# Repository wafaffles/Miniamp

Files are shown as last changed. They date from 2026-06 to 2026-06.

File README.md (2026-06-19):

# Miniamp
A portable, battery powered Hi-Fi DAC and headphone amplifier.

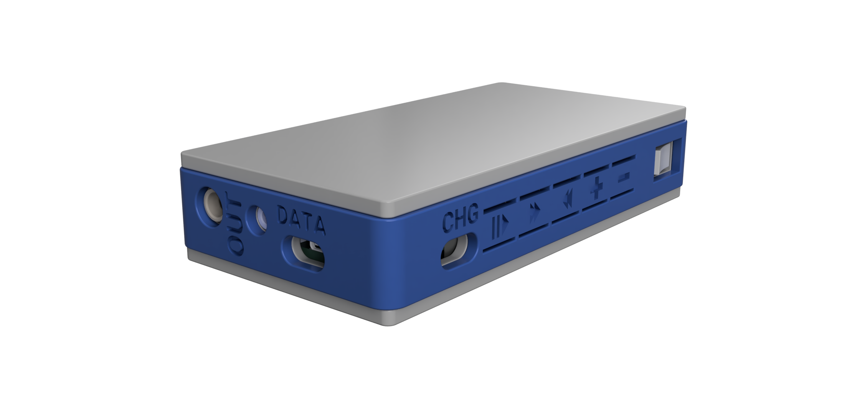
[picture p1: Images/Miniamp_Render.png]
Render of Miniamp in case


## Shortcuts
- [Features](#features)
- [What is it?](#what-is-it)
- [Resources](#resources)
- [Assembly](#assembly)
- [Bill Of Materials](#bill-of-materials)
- [Photos](#photos)

## Miniamp Zine

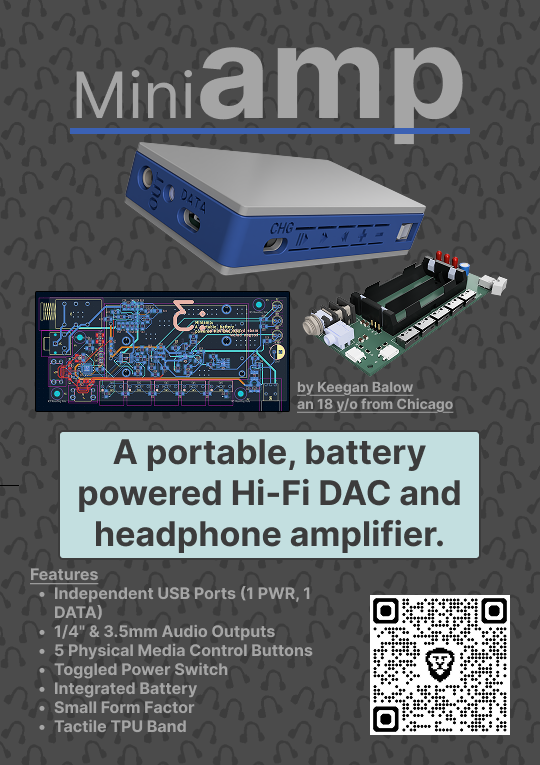
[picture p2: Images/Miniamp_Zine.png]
Miniamp Zine


## Features

- Independent USB-C Ports
  - Top Mounted Data Only USB-C
  - Side Mounted Power Only USB-C
- Variable Size Audio Outputs
  - 1/4"
  - 3.5mm
- 5 Physical Media Control Buttons
- Toggleable Power Switch
- 2 Integrated 18650 Batteries
  - Avoids Discharging Connected Device (e.g., Mobile Phone, Laptop)
- Small Form Factor

## What is it?

Miniamp is a portable, battery powered DAC and headphone amp designed for phones, portable devices, or for desk deployments. The Miniamp features a Hifi DAC chip capable of producing 24bit 44.1kHz outputs at 2.1Vrms, with adequite power for majority of headphones. It utilizes a Silicon Labs CP2615-A02-GM USB to I2S chip, a Cirrus Logic WM8524CGEDT DAC, and an Analog Devices MAX97220AETE+T headphone amplifier. It also has a battery charging and protection circuit to handle charing, protection, and output regulation to the ICs using 2 18650 batteries in a 1s2p configuration. This setup removes power draw from the data streaming device and offloads it to the batteries, with a passthrough power circuit to power all devices externally with a long battery life.

I created this to have an easy device to bring around with me at school so I can use my wired headphones and control them without the need to open my phone for controls or worry about my phone dying which was really nice. It should work well and do exactly that since I love the apple dongle, but its just super small, feels like its gonna break, and just kinda basic without any controls.
 
## Resources

CAD Link: https://cad.onshape.com/documents/a14a9a55c78bf32f82e1c97a/w/0351478092a46614c60a771f/e/1fa4c67b30b50298fb86e419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

CAD Files: [HERE](/3DModels)

ECAD Files: [HERE](/Models/ECADModels_Production/)

Production Files: [HERE](/Resources/)

## Assembly

You will need:
- PCB (PCBA with ICs attached if you do not have a way to solder smd parts without legs, the assumed method of this assembly guide)
- Rest of ICS needed
- Required Heatset Inserts
- All printed parts
- Soldering iron
- Solder
- Matching screwdriver to screw set (allen key in provided kit)
- Small pair of tweasers

1. Gather all resources, print all case parts, and have a clean open workspace
2. Carefully solder all components not installed with PCBA according to the schematics and ECAD files (most resistors, caps, and all THT parts)
3. With the PCB assembled now, to start assembling the case you want to heat your soldering iron to about 225°C and carefully insert the M3 heatset inserts into the standoffs on the top case part.
4. Now that both the case is assembled and ready, and the PCB is ready, test the PCB outside of its case to ensure it will work without issue. If there is an error, seek help or investigate to make sure all components are placed correctly.
5. Insert the PCB into the top case, slide on the TPU band, and screw in the bottom case using the 4 M3 bolts
6. Enjoy!

## Bill Of Materials

BOM: [HERE](https://docs.google.com/spreadsheets/d/1Rq9yz0U521aMRGwPaQNTlH2bsf_DakTQIQjvENSfLP8/edit?usp=sharing)

PCBA BOM: [HERE](https://docs.google.com/spreadsheets/d/17-cePCVTrSii_cqeCaBxXgTqAQEytrTk/edit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)

Both can be found in files, normal BOM [here](/Resources/) and the PCBA BOM [here](/Models/ECADModels_Production/)

## Photos

Miniamp Main PCB Schematic

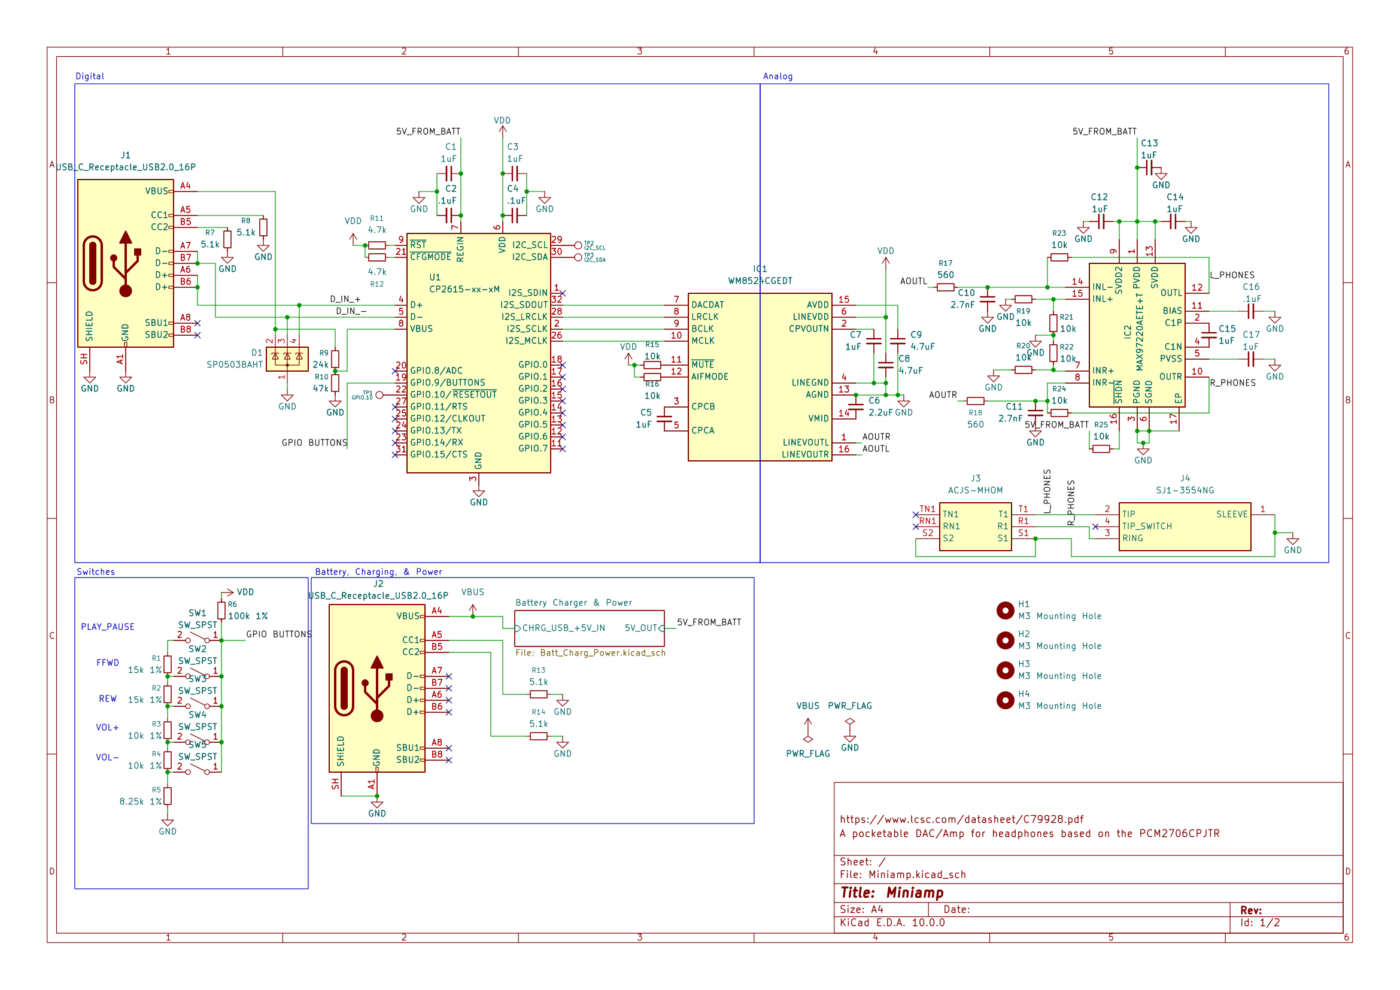
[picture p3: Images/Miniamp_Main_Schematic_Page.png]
Miniamp Main PCB Schematic


Miniamp Power PCB Schematic

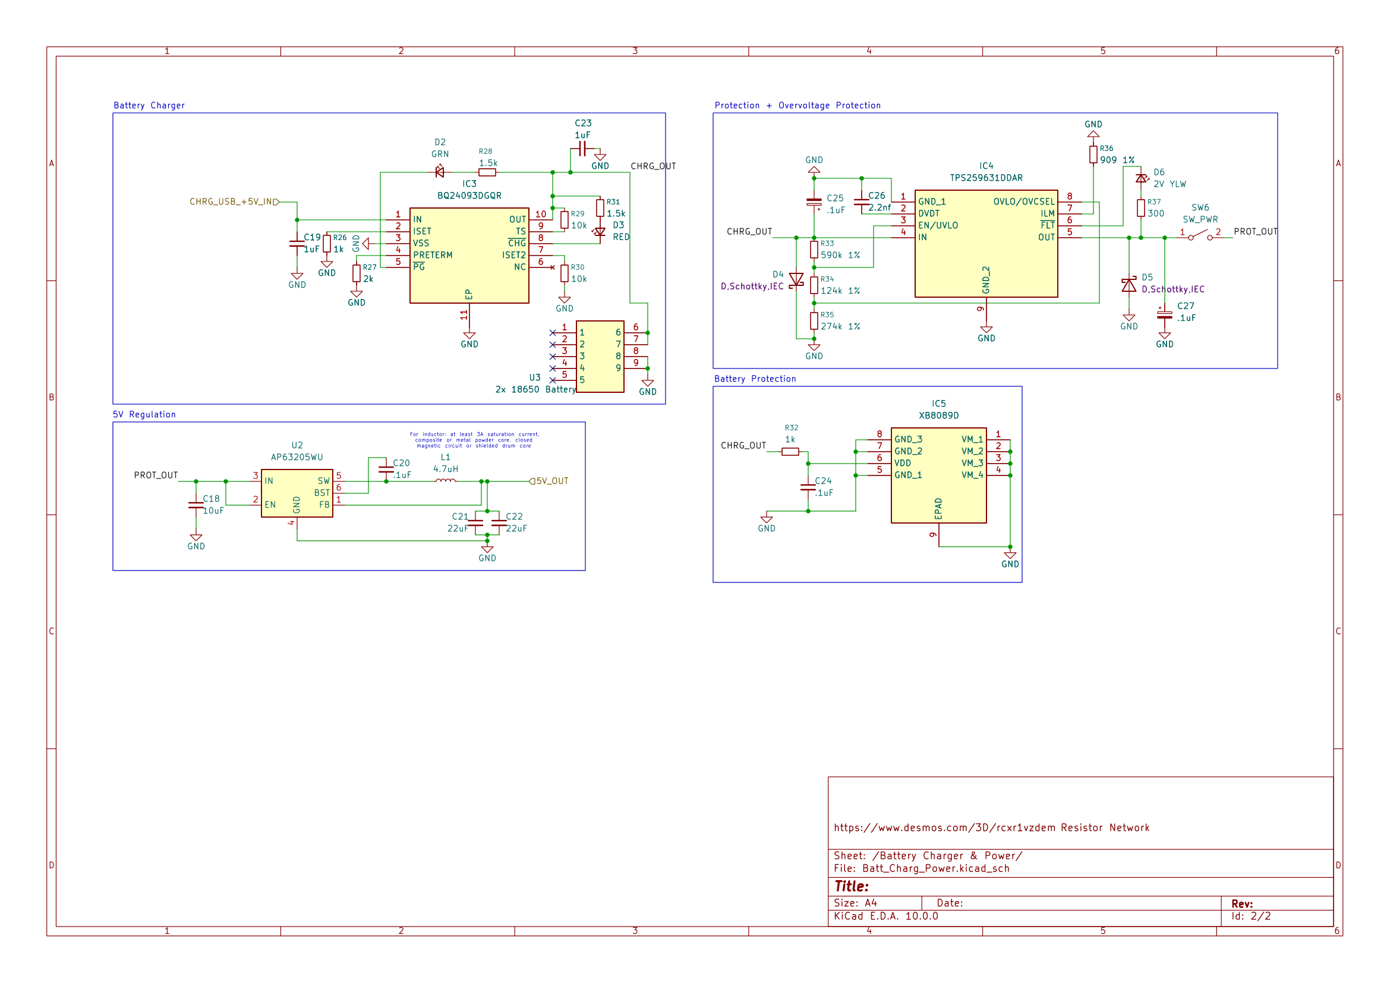
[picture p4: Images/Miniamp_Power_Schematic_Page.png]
Miniamp Power PCB Schematic


Miniamp Case Front

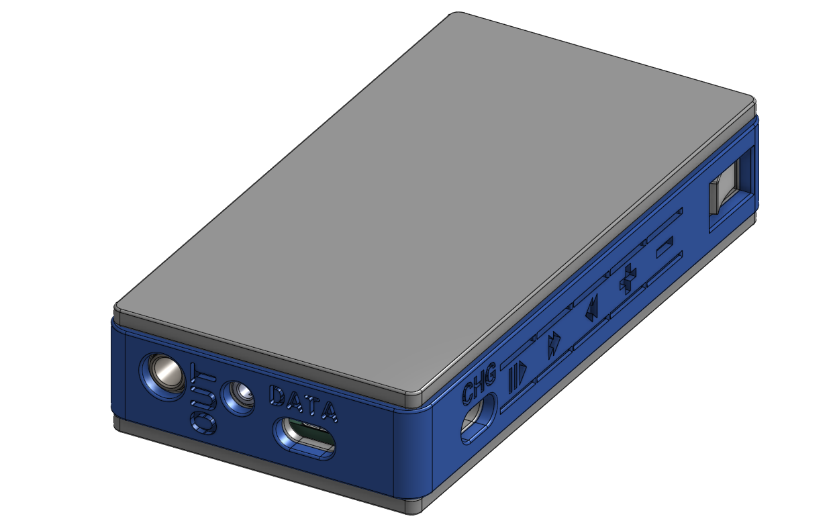
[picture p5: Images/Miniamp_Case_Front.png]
Miniamp Case Front


Miniamp Case Back

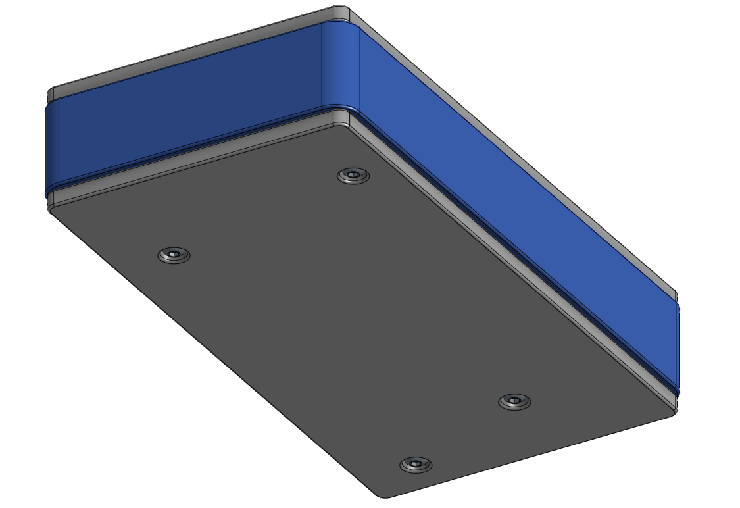
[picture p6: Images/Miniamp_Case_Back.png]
Miniamp Case Back


Miniamp Case Inside

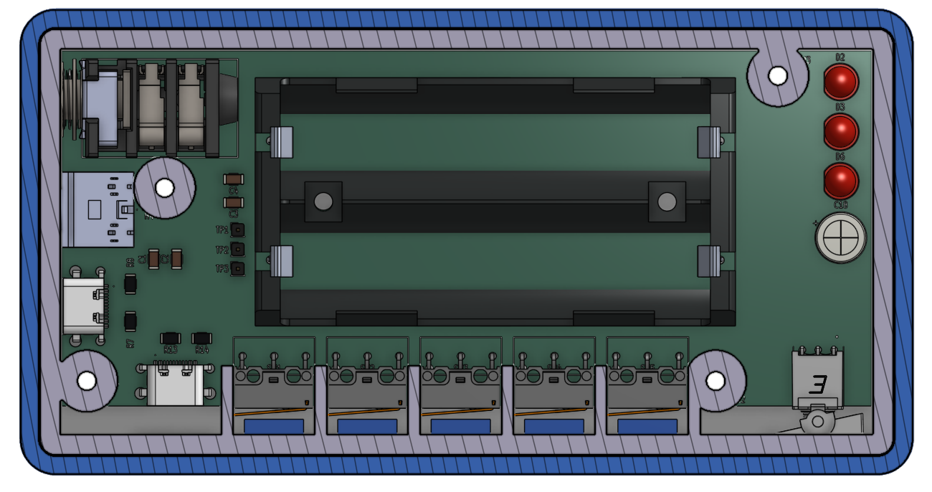
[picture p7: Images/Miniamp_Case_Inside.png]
Miniamp Case Inside


PCB All Layers

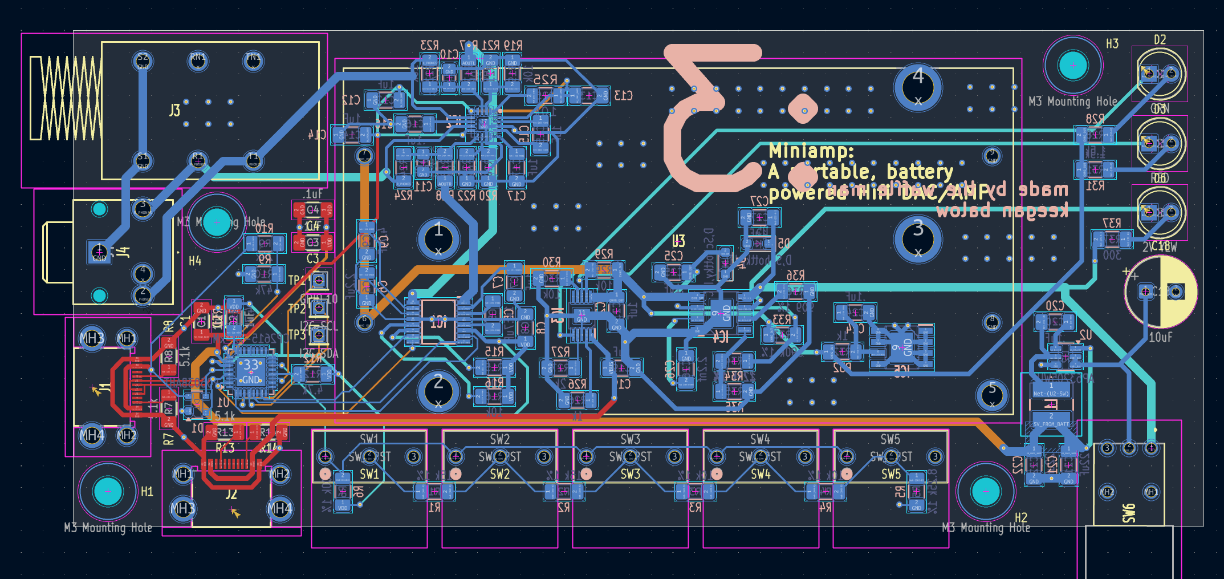
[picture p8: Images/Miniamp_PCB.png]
PCB All Layers


PCB F.Cu Layer

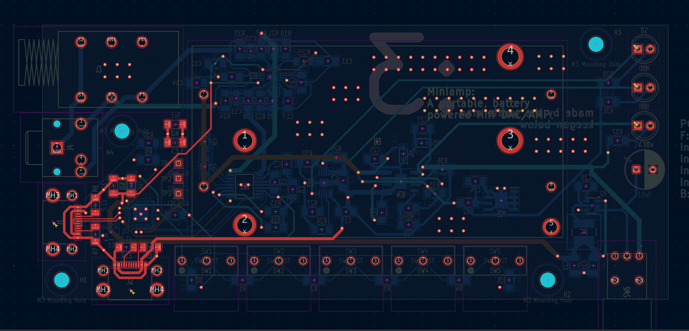
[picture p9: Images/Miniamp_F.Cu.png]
PCB F.Cu Layer


PCB In1.Cu Layer

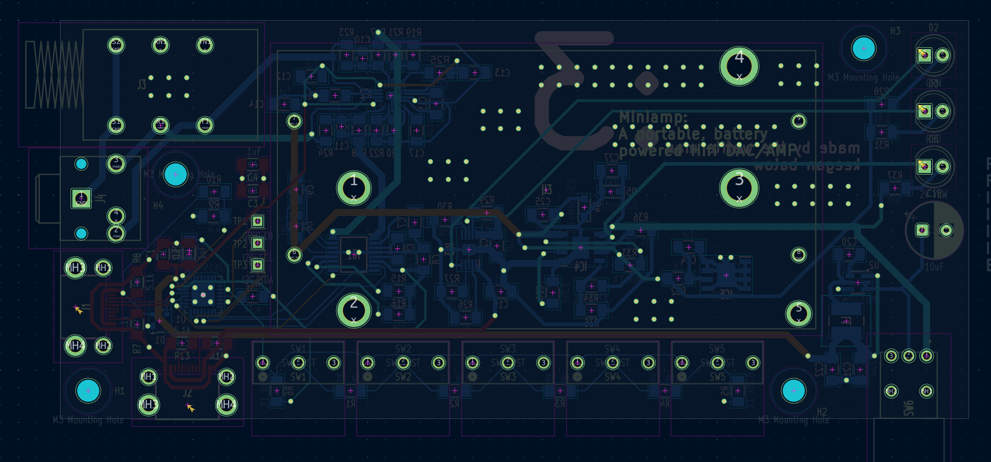
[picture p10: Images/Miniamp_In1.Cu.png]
PCB In1.Cu Layer


PCB In2.Cu Layer

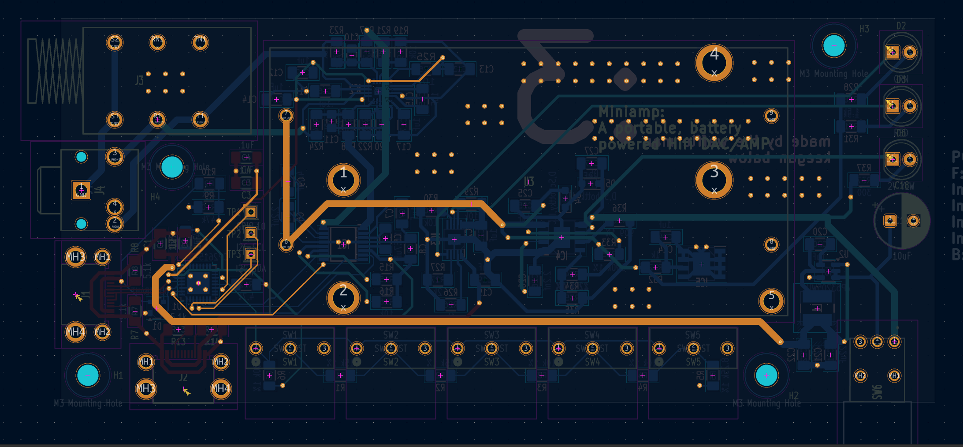
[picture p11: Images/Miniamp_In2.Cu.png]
PCB In2.Cu Layer


PCB In3.Cu Layer

PCB In3.Cu Layer

PCB In4.Cu Layer

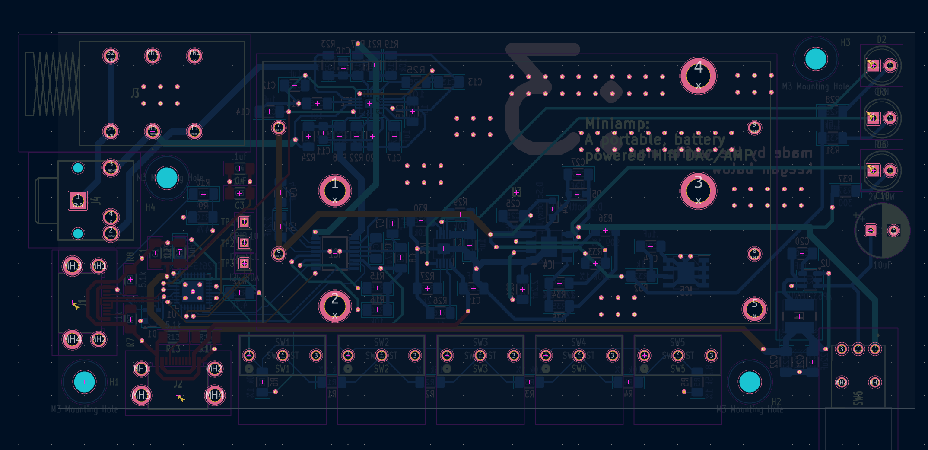
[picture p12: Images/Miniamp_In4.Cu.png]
PCB In4.Cu Layer


PCB B.Cu Layer

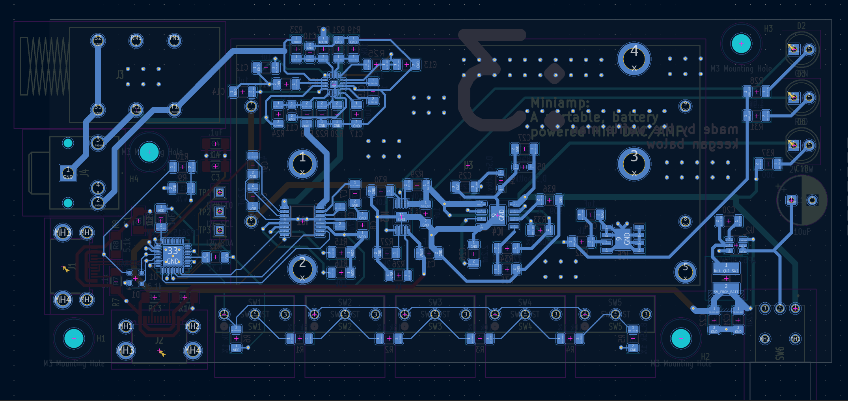
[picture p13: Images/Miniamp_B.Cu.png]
PCB B.Cu Layer


Top of PCB

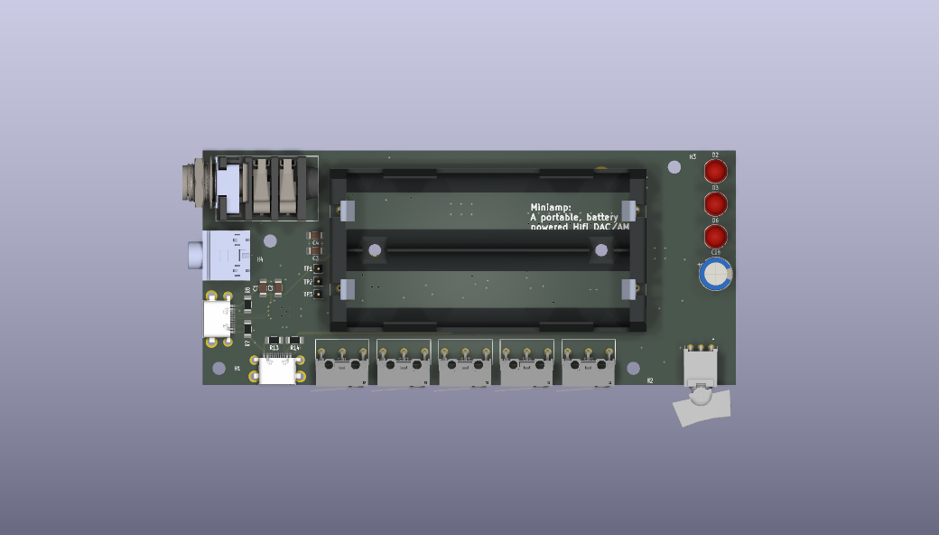
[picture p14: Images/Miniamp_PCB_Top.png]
Top of PCB


Bottom of PCB

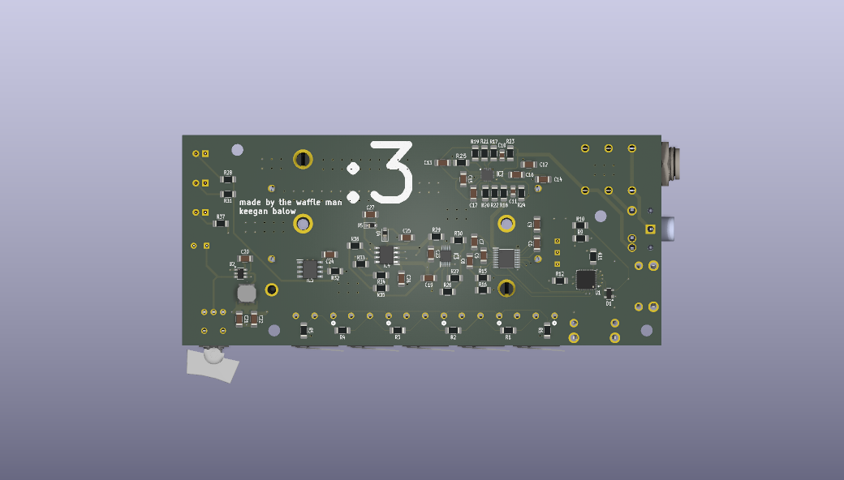
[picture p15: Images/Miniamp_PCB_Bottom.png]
Bottom of PCB


Render of PCB

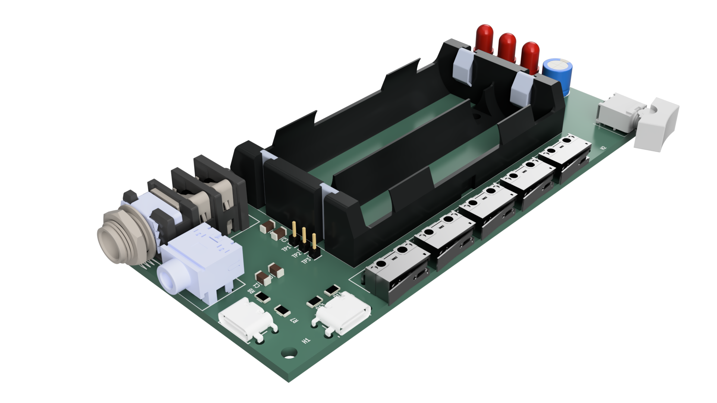
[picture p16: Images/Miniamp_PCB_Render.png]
Render of PCB


## Credits

This project uses:

- [KiCad](https://www.kicad.org/)
- [Figma](https://www.figma.com/)
- [Hack Club Fallout](https://fallout.hackclub.com/path)

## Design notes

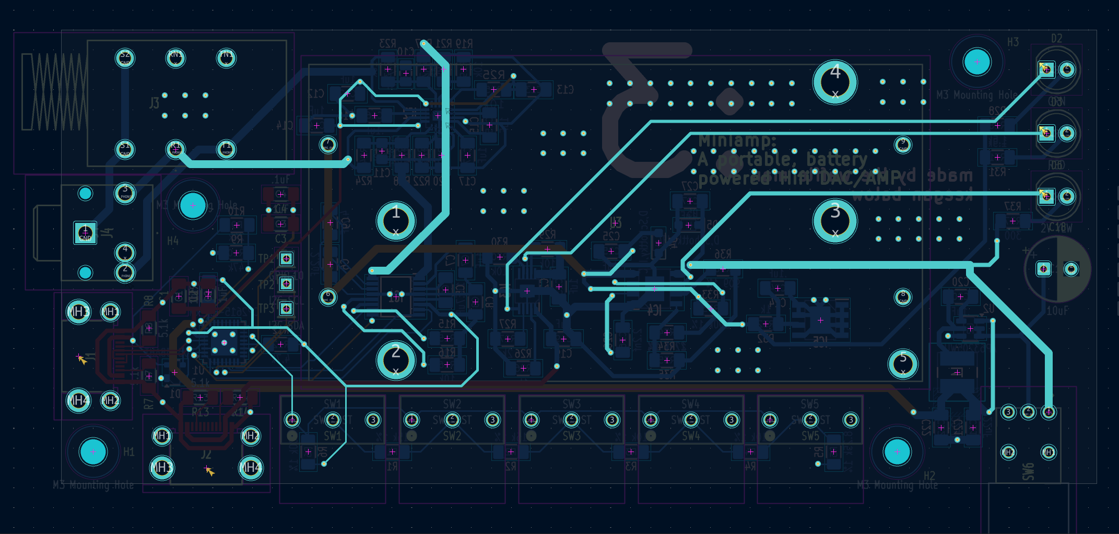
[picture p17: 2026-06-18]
Images/Miniamp_In3.Cu.png

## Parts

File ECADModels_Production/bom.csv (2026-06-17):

Designator | Footprint | Quantity | Value | LCSC Part #
C1, C12, C13, C14, C15, C17, C19, C23, C3, C5, C7 | 1206 | 11 | 1uF | C318771
C10, C11 | 0805 | 2 | 2.7nF
C16, C2, C20, C24, C25, C27, C4 | 1206 | 7 | .1uF
C18 | CP_Radial_D8.0mm_P3.50mm | 1 | 10uF | C2168319
C21, C22 | 1206 | 2 | 22uF
C26 | 1206 | 1 | 2.2nf
C6 | 1206 | 1 | 2.2uF
C8, C9 | 1206 | 2 | 4.7uF
D1 | SOT-143 | 1 | SP0503BAHT | C7074
D2 | LED_D5.0mm | 1 | GRN
D3 | LED_D5.0mm | 1 | RED
D4, D5 | D_SOD-323_HandSoldering | 2 | D,Schottky,IEC | C2762697
D6 | LED_D5.0mm | 1 | 2V YLW
IC1 | SOP65P640X120-16N | 1 | WM8524CGEDT | C146242
IC2 | QFN50P300X300X80-17N | 1 | MAX97220AETE+T | C2682711
IC3 | SOP50P490X110-11N | 1 | BQ24093DGQR | C2871988
IC4 | SOIC127P600X170-9N | 1 | TPS259631DDAR | C2155778
IC5 | SOIC127P605X175-9N | 1 | XB8089D | C79928
J1, J2 | UJ20CHGMSMT2BP16TR | 2 | USB_C_Receptacle_USB2.0_16P
J3 | ACJSMHOM | 1 | ACJS-MHOM
J4 | SJ13554NG | 1 | SJ1-3554NG
L1 | SDCH1V50404R7MR | 1 | 4.7uH
R1, R2 | 1206 | 2 | 15k 1%
R10 | 1206 | 1 | 47k
R11, R12 | 1206 | 2 | 4.7k
R13, R14, R7, R8 | 1206 | 4 | 5.1k
R15, R16, R19, R20, R21, R22, R23, R24, R25, R29, R30 | 1206 | 11 | 10k | C871997
R17, R18 | 1206 | 2 | 560 | C872823
R26, R32 | 1206 | 2 | 1k
R27 | 1206 | 1 | 2k
R28, R31 | 1206 | 2 | 1.5k
R3, R4 | 1206 | 2 | 10k 1%
R33 | 1206 | 1 | 590k 1%
R34 | 1206 | 1 | 124k 1%
R35 | 1206 | 1 | 274k 1%
R36 | 1206 | 1 | 909 1%
R37 | 1206 | 1 | 300
R5 | 1206 | 1 | 8.25k 1%
R6 | 1206 | 1 | 100k 1%
R9 | 1206 | 1 | 24k
SW1, SW2, SW3, SW4, SW5 | ZMA00A150L04RC | 5 | SW_SPST
SW6 | 400AWMSP1R1BLKM6QE | 1 | SW_PWR
TP1 | PinHeader_1x01_P2.00mm_Vertical | 1 | GPIO.10
TP2 | PinHeader_1x01_P2.00mm_Vertical | 1 | I2C_SCL
TP3 | PinHeader_1x01_P2.00mm_Vertical | 1 | I2C_SDA
U1 | QFN-32-1EP_5x5mm_P0.5mm_EP3.3x3.3mm | 1 | CP2615-xx-xM | C1521596
U2 | TSOT-23-6 | 1 | AP63205WU | C2071056
U3 | 1049 | 1 | 2x 18650 Battery

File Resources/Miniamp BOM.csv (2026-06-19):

Product Name | Vendor | Part Number | Desc | Link | Unit Price | Qty | Total Price | Running Total | Already Owned?
Cylindrical Battery Contacts, Clips, Holders & Springs 18650 DUAL THM BATTERY HOLDER | Mouser | 1049 |  | https://www.mouser.com/ProductDetail/Keystone-Electronics/1049?qs=%2F7TOpeL5Mz78b0pqEFIl5w%3D%3D | $6.17 | 1 | $6.17 | $6.17 | FALSE
Phone Connectors 1/4"HOR Snap-fit CHASSIS CONN | Mouser | ACJS-MHOM |  | https://www.mouser.com/ProductDetail/Amphenol/ACJS-MHOM?qs=t8VhaDIDl4vZ9ROsgrVY0w%3D%3D | $1.15 | 1 | $1.15 | $7.32 | FALSE
Phone Connectors Audio Jacks | Mouser | SJ1-3554NG |  | https://www.mouser.com/ProductDetail/Same-Sky/SJ1-3554NG?qs=WyjlAZoYn50FPSMJgVuxug%3D%3D | $1.12 | 1 | $1.12 | $8.44 | FALSE
USB Connectors USB Jack, Type C, 2.0, MSMT, Horizontal, Gold Flash, 16 Pin, TR | Mouser | UJ20-C-H-G-MSMT-2B-P16-TR |  | https://www.mouser.com/ProductDetail/Same-Sky/UJ20-C-H-G-MSMT-2B-P16-TR?qs=6avfeC6zeS7u%252BNINt00UrA%3D%3D | $0.47 | 2 | $0.94 | $9.38 | FALSE
Power Inductors - SMD 4.7 UH 20% | Mouser | SDCH1V5040-4R7M-R |  | https://www.mouser.com/ProductDetail/Eaton/SDCH1V5040-4R7M-R?qs=TuK3vfAjtkWxzjAZQpI5RQ%3D%3D | $0.17 | 2 | $0.34 | $9.72 | FALSE
Rocker Switches Sealed Rocker Switch SPDT 3A 120V | Mouser | 400AWMSP1R1BLKM6QE |  | https://www.mouser.com/ProductDetail/E-Switch/400AWMSP1R1BLKM6QE?qs=f57gQzlyLiqt3jLeaZTxLw%3D%3D | $3.92 | 1 | $3.92 | $13.64 | FALSE
Multilayer Ceramic Capacitors MLCC - SMD/SMT 2200pF +-5% 50V | Mouser | 1206N222J500CT |  | https://www.mouser.com/ProductDetail/Walsin/1206N222J500CT?qs=ZrPdAQfJ6DNDIm3g%252BmD%2FDA%3D%3D | $0.17 | 2 | $0.34 | $13.98 | FALSE
Multilayer Ceramic Capacitors MLCC - SMD/SMT 22uF+/-20% 16V X5R 3 1206 | Mouser | CL31A226MOCLNNC |  | https://www.mouser.com/ProductDetail/Samsung-Electro-Mechanics/CL31A226MOCLNNC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 | $0.25 | 4 | $1.00 | $14.98 | FALSE
Aluminum Electrolytic Capacitors - Radial Leaded WCAP-PTHR 10uF 80V 20% Radial | Mouser | 870056174001 |  | https://www.mouser.com/ProductDetail/Wurth-Elektronik/870056174001?qs=qpJ%252B%252B%252Bdg6p0KYLmtcsurBg%3D%3D | $1.38 | 2 | $2.76 | $17.74 | FALSE
Basic / Snap Action Switches Detect | Mouser | ZMA00A150L04RC |  | https://www.mouser.com/ProductDetail/CK-Switches/ZMA00A150L04RC?qs=vOd3edNlRKCBpE45lgpGig%3D%3D | $1.31 | 7 | $9.17 | $26.91 | FALSE
Multilayer Ceramic Capacitors MLCC - SMD/SMT 2.2uF +-10% 25V | Mouser | 1206X225K250CT |  | https://www.mouser.com/ProductDetail/Walsin/1206X225K250CT?qs=fIkAfuXiAQIiAdqjc7MDvw%3D%3D | $0.19 | 2 | $0.38 | $27.29 | FALSE
Multilayer Ceramic Capacitors MLCC - SMD/SMT 4.7uF+/-10% 16V X5R 1206 | Mouser | CL31A475KOHNNNE |  | https://www.mouser.com/ProductDetail/Samsung-Electro-Mechanics/CL31A475KOHNNNE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 | $0.21 | 4 | $0.84 | $28.13 | FALSE
Film Capacitors .0027uF 50VDC 2% PPS FILM 0805 | Mouser | ECH-U1H272GX5 |  | https://www.mouser.com/ProductDetail/Panasonic/ECH-U1H272GX5?qs=DWeLBnRir%2FJzz9yLS1hFOg%3D%3D | $0.56 | 4 | $2.24 | $30.37 | FALSE
Single Color LEDs Red Oval LED | Mouser | C5SMF-RJF-CT0W0BB2 |  | https://www.mouser.com/ProductDetail/Cree-LED/C5SMF-RJF-CT0W0BB2?qs=vnbNJPHmPnMRCSh39bwmBg%3D%3D | $0.16 | 1 | $0.16 | $30.53 | FALSE
Single Color LEDs Green Oval LED | Mouser | C5SMF-GJF-CV0Y0791 |  | https://www.mouser.com/ProductDetail/Cree-LED/C5SMF-GJF-CV0Y0791?qs=1sbE9T7hb3bLY9RhY5fsuw%3D%3D | $0.23 | 1 | $0.23 | $30.76 | FALSE
Single Color LEDs Yellow Diffused | Mouser | LTL-307Y |  | https://www.mouser.com/ProductDetail/LITEON/LTL-307Y?qs=LJdOdOP975yN06YmF7ulEw%3D%3D | $0.19 | 1 | $0.19 | $30.95 | FALSE
Thin Film Resistors - SMD 1/4W 15K ohm 1% 50ppm | Mouser | RT1206FRE0715KL |  | https://www.mouser.com/ProductDetail/YAGEO/RT1206FRE0715KL?qs=fd0Ij%252BN8svyW6WTDZBxZXg%3D%3D | $0.10 | 4 | $0.40 | $31.35 | FALSE
Thin Film Resistors - SMD 1/4W 47K ohm 1% 50ppm | Mouser | RT1206FRE0747KL |  | https://www.mouser.com/ProductDetail/YAGEO/RT1206FRE0747KL?qs=yNCrj0CQcyLtiZj5c%252Bb6HQ%3D%3D | $0.10 | 2 | $0.20 | $31.55 | FALSE
Thin Film Resistors - SMD 4.7K Ohm 1% 1/4W 200 Volts 50ppm | Mouser | RT1206FRE074K7L |  | https://www.mouser.com/ProductDetail/YAGEO/RT1206FRE074K7L?qs=yNCrj0CQcyLcoH%2FB%252BiP%2FFQ%3D%3D | $0.10 | 4 | $0.40 | $31.95 | FALSE
Thin Film Resistors - SMD 1/4W 5.1K Ohms 0.5% 1206 25ppm | Mouser | RG3216P-5101-D-T5 |  | https://www.mouser.com/ProductDetail/Susumu/RG3216P-5101-D-T5?qs=nCAm%252BcMdy9wuhfaraXCW3Q%3D%3D | $0.13 | 8 | $1.04 | $32.99 | FALSE
Thin Film Resistors - SMD 1K OHM .5% 50PPM 1/4W | Mouser | RT1206DRE071KL |  | https://www.mouser.com/ProductDetail/YAGEO/RT1206DRE071KL?qs=8cPjvKtxWv5SkxceGfpDGg%3D%3D | $0.10 | 4 | $0.40 | $33.39 | FALSE
Thin Film Resistors - SMD 2KOhms 1206 0.5W 100ppm 1% Hi Pwr Anti-Sulfur | Mouser | RNCP1206FTD2K00 |  | https://www.mouser.com/ProductDetail/SEI-Stackpole/RNCP1206FTD2K00?qs=FESYatJ8odJdO%252Bi%252BIQeoAw%3D%3D | $0.10 | 2 | $0.20 | $33.59 | FALSE
Thin Film Resistors - SMD 1.5K OHM .5% 50PPM 1/4W | Mouser | RT1206DRE071K5L |  | https://www.mouser.com/ProductDetail/YAGEO/RT1206DRE071K5L?qs=yNCrj0CQcyLalOXKouyj7Q%3D%3D | $0.10 | 4 | $0.40 | $33.99 | FALSE
Thin Film Resistors - SMD 10K OHM 1% 25PPM 1/4W | Mouser | RT1206FRD0710KL |  | https://www.mouser.com/ProductDetail/YAGEO/RT1206FRD0710KL?qs=Fz%2FrpjPuTcHnXCbM3bUnCw%3D%3D | $0.10 | 4 | $0.40 | $34.39 | FALSE
Thin Film Resistors - SMD 1/4W 590K Ohms 0.1% 1206 25ppm | Mouser | RG3216P-5903-B-T5 |  | https://www.mouser.com/ProductDetail/Susumu/RG3216P-5903-B-T5?qs=nCAm%252BcMdy9w46vMZTR8eAw%3D%3D | $0.25 | 2 | $0.50 | $34.89 | FALSE
Thin Film Resistors - SMD 1/4W 124K ohm 1% 50ppm | Mouser | RT1206FRE07124KL |  | https://www.mouser.com/ProductDetail/YAGEO/RT1206FRE07124KL?qs=8cPjvKtxWv4EJBjJ%252BKBBMQ%3D%3D | $0.10 | 2 | $0.20 | $35.09 | FALSE
Thin Film Resistors - SMD 1/4W 274K Ohms 0.1% 1206 25ppm | Mouser | RG3216P-2743-B-T1 |  | https://www.mouser.com/ProductDetail/Susumu/RG3216P-2743-B-T1?qs=9aRBpVNfmq6PStZS%2Fg4bQA%3D%3D | $0.25 | 2 | $0.50 | $35.59 | FALSE
Thin Film Resistors - SMD 1/4W 909 ohm .1% 25ppm | Mouser | RT1206BRD07909RL |  | https://www.mouser.com/ProductDetail/YAGEO/RT1206BRD07909RL?qs=yNCrj0CQcyIkVQOgdGDRew%3D%3D | $0.21 | 2 | $0.42 | $36.01 | FALSE
Thin Film Resistors - SMD 1/4W 300 ohm .1% 25ppm | Mouser | RT1206BRD07300RL |  | https://www.mouser.com/ProductDetail/YAGEO/RT1206BRD07300RL?qs=yNCrj0CQcyJPwyNWLJZVSA%3D%3D | $0.21 | 2 | $0.42 | $36.43 | FALSE
Thin Film Resistors - SMD 1/4W 8.25K ohm 1% 50ppm | Mouser | RT1206FRE078K25L |  | https://www.mouser.com/ProductDetail/YAGEO/RT1206FRE078K25L?qs=Fz%2FrpjPuTcHPRil1Gecshg%3D%3D | $0.10 | 2 | $0.20 | $36.63 | FALSE
Thin Film Resistors - SMD 100KOhms 1206 0.5W 100ppm 1% HiPwr Anti-Sulfur | Mouser | RNCP1206FTD100K |  | https://www.mouser.com/ProductDetail/SEI-Stackpole/RNCP1206FTD100K?qs=IPgv5n7u5QazQN1PXtwDJg%3D%3D | $0.10 | 2 | $0.20 | $36.83 | FALSE
Thin Film Resistors - SMD 1/4W 24K Ohms 0.5% 1206 25ppm | Mouser | RG3216P-2402-D-T5 |  | https://www.mouser.com/ProductDetail/Susumu/RG3216P-2402-D-T5?qs=9aRBpVNfmq5VSrAQlOVAVg%3D%3D | $0.13 | 2 | $0.26 | $37.09 | FALSE
Mouser Shipping | Mouser | SHIP |  | N/A | $8.49 | 1 | $8.49 | $45.58 | FALSE
Mouser Fees/Taxes/Import | Mouser | FEE |  | N/A | $10.20 | 1 | $10.20 | $55.78 | FALSE
JLC PCBs | JLCPCB | N/A | PCBs | N/A | $54.80 | 1 | $54.80 | $110.58 | FALSE
JLCPCB PCBA | JLCPCB | N/A | PCBA service fees | N/A | $127.05 | 1 | $127.05 | $237.63 | FALSE
JLCPCB Shipping | JLCPCB | SHIP | JLCPCB Shipping | N/A | $45.76 | 1 | $45.76 | $283.39 | FALSE
JLCPCB Fees/Taxes/Import | JLCPCB | FEE | JLCPCB Fees/Taxes/Import | N/A | $63.04 | 1 | $63.04 | $346.43 | FALSE
OVERTURE TPU Filament 1.75mm Flexible Roll, 95A Soft 3D Printer Filament, 1kg Spool (2.2 lbs), Fit Most FDM Printer (TPU Blue) | Amazon | N/A | 1Kg Overture Blue 95A TPU | https://a.co/d/04cSuq9N | $24.99 | 1 | $24.99 | $371.42 | FALSE
ELEGOO Matte PLA Filament Matte Black 1KG, 1.75mm 3D Printer Filament Dimensional Accuracy +/- 0.02mm, 1kg Carboard Spool (2.2lbs) Fits for Most FDM 3D Printers | Amazon | N/A | 1Kg Elegoo Matte Black PLA | https://www.amazon.com/dp/B0CFV3WF7P | $16.99 | 1 | $16.99 | $388.41 | TRUE
VIGRUE 570Pcs M5 M4 M3 Button Head Socket Cap Screws Bolts Nuts Washers Assortment Kit, Black Small Metric Screws Set Assortment, 10.9 Grade Alloy Steel | Amazon | N/A | Assorted bolt set I already have with M4 bolts | https://www.amazon.com/dp/B07HVRJW5J | $21.99 | 1 | $21.99 | $410.40 | TRUE
Hilitchi 460 Pcs M2 M3 M4 M5 Female Thread Brass Knurled Threaded Insert Embedment Nuts Assortment Kit, Embed Parts, Pressed Fit into Holes for 3D Prints and More Projects | Amazon | N/A | Assorted heatset inswrt set I already have with M4 heatset inserts | https://www.amazon.com/dp/B07VFZWWXY | $20.99 | 1 | $20.99 | $431.39 | TRUE
 |  |  |  |  |  |  | Total | $431.39
 |  |  |  |  |  |  | Total To Buy | $371.42

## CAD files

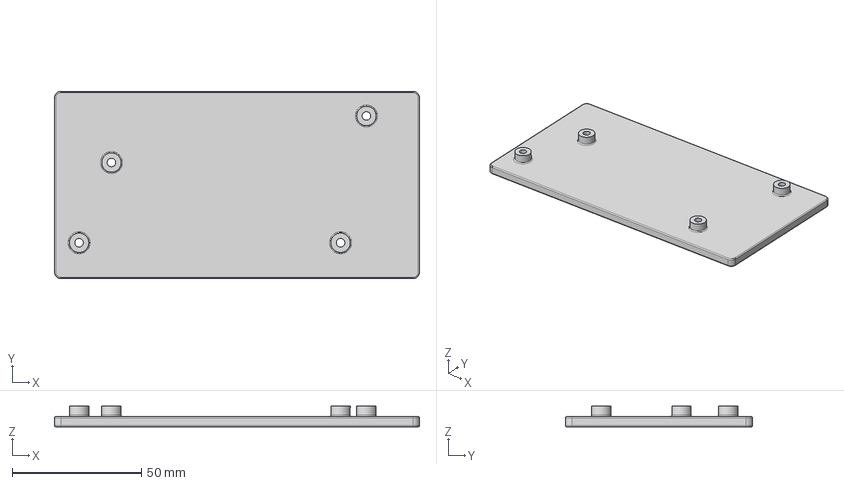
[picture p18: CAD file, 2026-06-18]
3DModels/Case_PS - Case_Bottom.step
141.0 x 72.4 x 8.00 mm

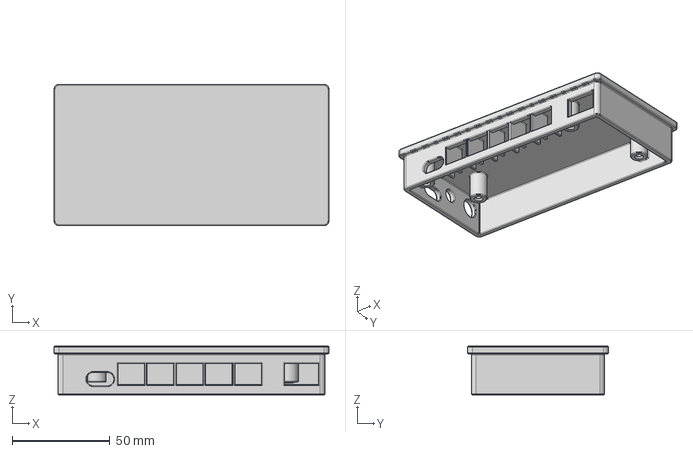
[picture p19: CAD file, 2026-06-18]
3DModels/Case_PS - Case_Top.step
141.0 x 72.4 x 25.0 mm

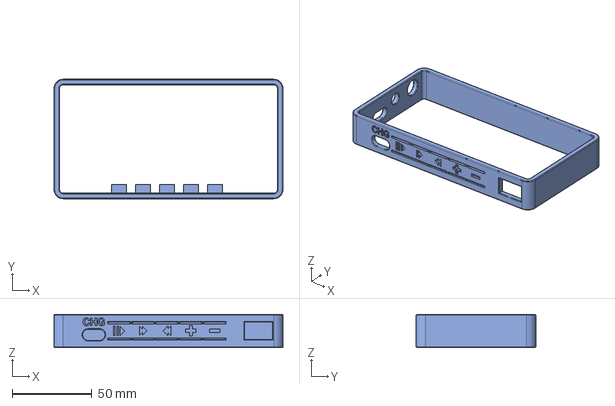
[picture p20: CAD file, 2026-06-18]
3DModels/Case_PS - TPU_Band.step
143.6 x 75.0 x 21.0 mm

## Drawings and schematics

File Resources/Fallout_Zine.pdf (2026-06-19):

# Miniamp

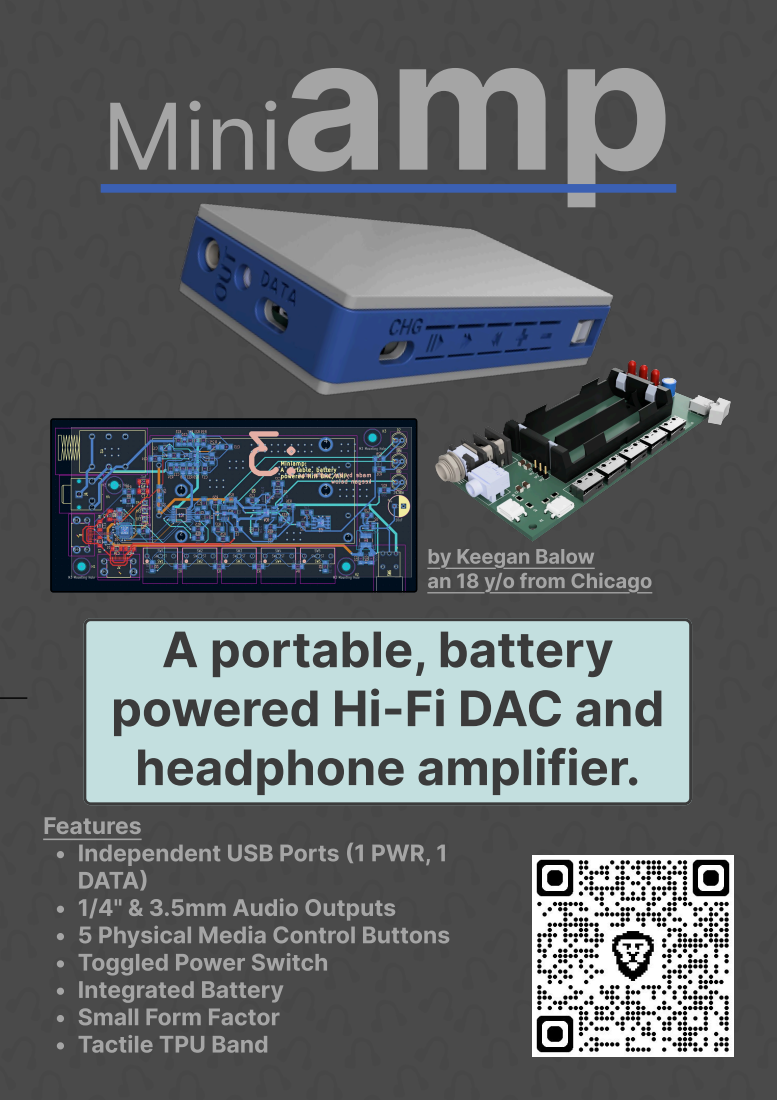
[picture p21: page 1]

by Keegan Balow
an 18 y/o from Chicago

A portable, battery
powered Hi-Fi DAC and
headphone amplifier.

Features
Independent USB Ports (1 PWR, 1
DATA)
1/4" & 3.5mm Audio Outputs
5 Physical Media Control Buttons
Toggled Power Switch
Integrated Battery
Small Form Factor
Tactile TPU band

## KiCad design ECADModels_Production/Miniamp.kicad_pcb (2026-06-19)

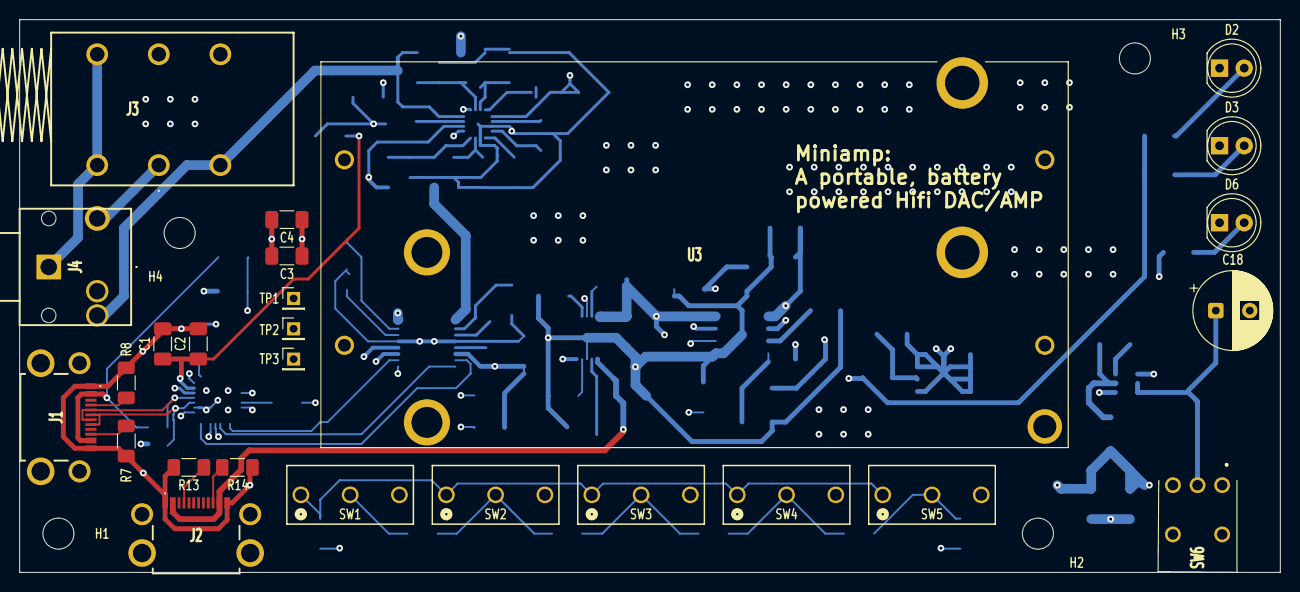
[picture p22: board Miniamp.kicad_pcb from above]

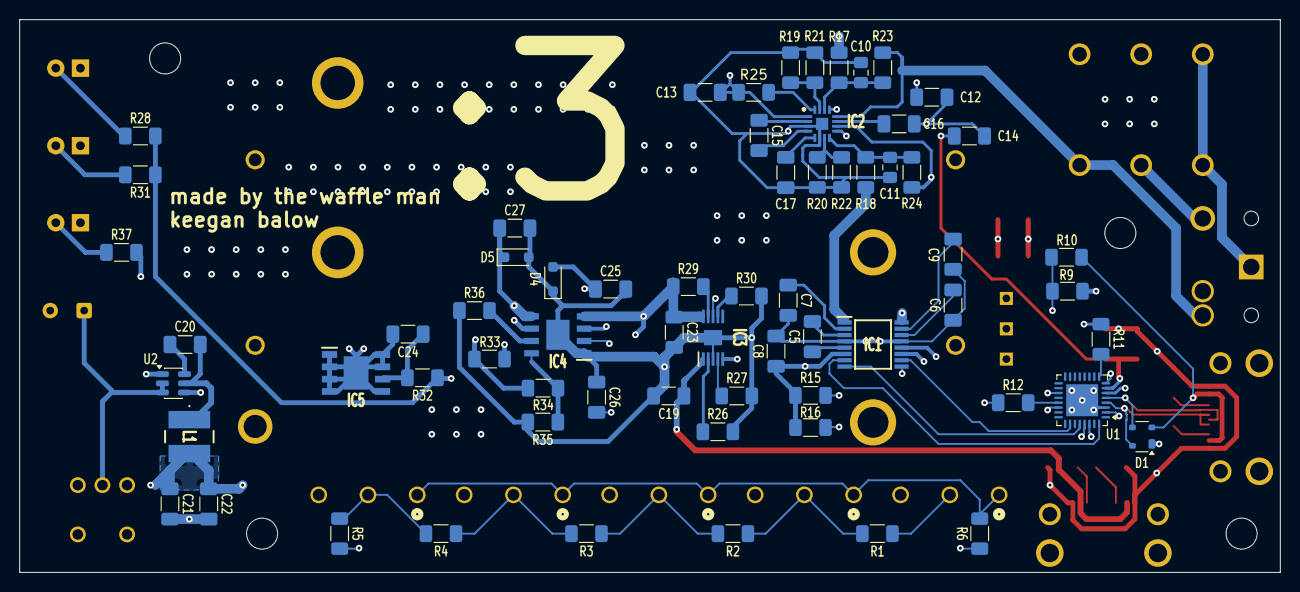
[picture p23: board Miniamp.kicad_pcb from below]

Board: 6 copper layers, 130.0 x 57.0 mm, 96 parts (66 on the bottom side), 67 nets.

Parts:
C1, C3, C5, C7, C12, C13, C14, C15, C17, C19, C23: 1uF; C_1206_3216Metric_Pad1.33x1.80mm_HandSolder
C2, C4, C16, C20, C24, C25, C27: .1uF; C_1206_3216Metric_Pad1.33x1.80mm_HandSolder
C6: 2.2uF; C_1206_3216Metric_Pad1.33x1.80mm_HandSolder
C8, C9: 4.7uF; C_1206_3216Metric_Pad1.33x1.80mm_HandSolder
C10, C11: 2.7nF; C_0805_2012Metric_Pad1.18x1.45mm_HandSolder
C18: 10uF; CP_Radial_D8.0mm_P3.50mm
C21, C22: 22uF; C_1206_3216Metric_Pad1.33x1.80mm_HandSolder
C26: 2.2nf; C_1206_3216Metric_Pad1.33x1.80mm_HandSolder
D1: SP0503BAHT; SOT-143
D2: GRN; LED_D5.0mm
D3: RED; LED_D5.0mm
D4, D5: D,Schottky,IEC; D_SOD-323_HandSoldering
D6: 2V YLW; LED_D5.0mm
H1, H2, H3, H4: M3 Mounting Hole; MountingHole_3.2mm_M3
IC1: WM8524CGEDT; SOP65P640X120-16N
IC2: MAX97220AETE+T; QFN50P300X300X80-17N
IC3: BQ24093DGQR; SOP50P490X110-11N
IC4: TPS259631DDAR; SOIC127P600X170-9N
IC5: XB8089D; SOIC127P605X175-9N
J1, J2: USB_C_Receptacle_USB2.0_16P; UJ20CHGMSMT2BP16TR
J3: ACJS-MHOM; ACJSMHOM
J4: SJ1-3554NG; SJ13554NG
L1: 4.7uH; SDCH1V50404R7MR
R1, R2: 15k 1%; R_1206_3216Metric_Pad1.30x1.75mm_HandSolder
R3, R4: 10k 1%; R_1206_3216Metric_Pad1.30x1.75mm_HandSolder
R5: 8.25k 1%; R_1206_3216Metric_Pad1.30x1.75mm_HandSolder
R6: 100k 1%; R_1206_3216Metric_Pad1.30x1.75mm_HandSolder
R7, R8, R13, R14: 5.1k; R_1206_3216Metric_Pad1.30x1.75mm_HandSolder
R9: 24k; R_1206_3216Metric_Pad1.30x1.75mm_HandSolder
R10: 47k; R_1206_3216Metric_Pad1.30x1.75mm_HandSolder
R11, R12: 4.7k; R_1206_3216Metric_Pad1.30x1.75mm_HandSolder
R15, R16, R19, R20, R21, R22, R23, R24, R25, R29, R30: 10k; R_1206_3216Metric_Pad1.30x1.75mm_HandSolder
R17, R18: 560; R_1206_3216Metric_Pad1.30x1.75mm_HandSolder
R26, R32: 1k; R_1206_3216Metric_Pad1.30x1.75mm_HandSolder
R27: 2k; R_1206_3216Metric_Pad1.30x1.75mm_HandSolder
R28, R31: 1.5k; R_1206_3216Metric_Pad1.30x1.75mm_HandSolder
R33: 590k 1%; R_1206_3216Metric_Pad1.30x1.75mm_HandSolder
R34: 124k 1%; R_1206_3216Metric_Pad1.30x1.75mm_HandSolder
R35: 274k 1%; R_1206_3216Metric_Pad1.30x1.75mm_HandSolder
R36: 909 1%; R_1206_3216Metric_Pad1.30x1.75mm_HandSolder
R37: 300; R_1206_3216Metric_Pad1.30x1.75mm_HandSolder
SW1, SW2, SW3, SW4, SW5: SW_SPST; ZMA00A150L04RC
SW6: SW_PWR; 400AWMSP1R1BLKM6QE
TP1: GPIO.10; PinHeader_1x01_P2.00mm_Vertical
TP2: I2C_SCL; PinHeader_1x01_P2.00mm_Vertical
TP3: I2C_SDA; PinHeader_1x01_P2.00mm_Vertical
U1: CP2615-xx-xM; QFN-32-1EP_5x5mm_P0.5mm_EP3.3x3.3mm
U2: AP63205WU; TSOT-23-6
U3: 2x 18650 Battery; 1049

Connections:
/5V_FROM_BATT: C1.1, C2.1, C12.2, C13.1, C14.2, C21.1, C22.1, IC2.1 (PVDD), IC2.9 (SVDD2), IC2.13 (SVDD), L1.2, R25.1, U1.7 (REGIN), U2.1 (FB)
/AOUTL: IC1.16 (LINEVOUTR), R17.1
/AOUTR: IC1.1 (LINEVOUTL), R18.1
/Battery Charger & Power/CHRG_OUT: C23.1, C25.1, D4.2 (A+), IC3.10 (OUT), IC4.4 (IN), R28.2, R29.1, R31.1, R32.1, R33.1, U3.6, U3.7
/Battery Charger & Power/PROT_OUT: C18.1, SW6.2 (B), U2.2 (EN), U2.3 (IN)
/D_IN_+: D1.4 (K), J1.A6 (D+), J1.B6 (D+), U1.4 (D+)
/D_IN_-: D1.3 (K), J1.A7 (D-), J1.B7 (D-), U1.5 (D-)
/GPIO BUTTONS: R6.2, SW1.1 (A), SW2.1 (A), SW3.1 (A), SW4.1 (A), SW5.1 (A), U1.19 (GPIO.9/BUTTONS)
/L_PHONES: IC2.12 (OUTL), J3.T1, J4.2 (TIP), R23.2
/R_PHONES: IC2.10 (OUTR), J3.R1, J4.3 (RING), R24.2
GND: C1.2, C2.2, C3.2, C4.2, C6.1, C7.2, C8.2, C9.2, C10.2, C11.2, C12.1, C13.2, C14.1, C16.2, C17.2, C18.2, C19.2, C21.2, C22.2, C23.2, C24.2, C25.2, C26.1, C27.2, D1.1 (A), D4.1 (K-), D5.2 (A+), IC1.4 (LINEGND), IC1.13 (AGND), IC2.3 (PGND), IC2.6 (SGND), IC2.17 (EP), IC3.3 (VSS), IC3.11 (EP), IC4.1 (GND_1), IC4.9 (GND_2), IC5.1 (VM_1), IC5.2 (VM_2), IC5.3 (VM_3), IC5.4 (VM_4), IC5.5 (GND_1), IC5.7 (GND_2), IC5.8 (GND_3), IC5.9 (EPAD), J1.A1 (GND), J1.B1 (GND), J2.A1 (GND), J2.B1 (GND), J3.S1, J3.S2, J4.1 (SLEEVE), R5.2, R7.2, R8.2, R10.2, R13.2, R14.2, R19.1, R20.1, R21.2, R22.1, R26.2, R27.2, R30.2, R35.2, R36.1, U1.3 (GND), U1.33 (GND), U2.4 (GND), U3.8, U3.9
unnamed: D1.2 (K), J1.A4 (VBUS), J1.B4 (VBUS), R9.1
unnamed: D2.2 (A), R28.1
unnamed: D2.1 (K), IC3.5 (~PG)
unnamed: D3.2 (A), R31.2
unnamed: D3.1 (K), IC3.8 (~CHG)
unnamed: C27.1, D5.1 (K-), IC4.5 (OUT), R37.2, SW6.1 (A)
unnamed: D6.2 (A), R37.1
unnamed: D6.1 (K), IC4.6 (~FLT)
unnamed: IC1.12 (AIFMODE), R16.2
unnamed: C9.1, IC1.15 (AVDD)
unnamed: IC1.9 (BCLK), U1.2 (I2S_SCLK)
unnamed: C5.2, IC1.5 (CPCA)
unnamed: C5.1, IC1.3 (CPCB)
unnamed: C7.1, IC1.2 (CPVOUTN)
unnamed: IC1.7 (DACDAT), U1.32 (I2S_SDOUT)
unnamed: IC1.8 (LRCLK), U1.28 (I2S_LRCLK)
unnamed: IC1.10 (MCLK), U1.26 (I2S_MCLK)
unnamed: C6.2, IC1.14 (VMID)
unnamed: IC1.11 (~MUTE), R15.2
unnamed: C16.1, IC2.11 (BIAS)
unnamed: C15.2, IC2.4 (C1N)
unnamed: C15.1, IC2.2 (C1P)
unnamed: IC2.15 (INL+), R19.2, R21.1
unnamed: C10.1, IC2.14 (INL-), R17.2, R23.1
unnamed: IC2.7 (INR+), R20.2, R22.2
unnamed: C11.1, IC2.8 (INR-), R18.2, R24.1
unnamed: C17.1, IC2.5 (PVSS)
unnamed: IC2.16 (~SHDN), R25.2
unnamed: IC3.7 (ISET2), R30.1
unnamed: IC3.2 (ISET), R26.1
unnamed: IC3.4 (PRETERM), R27.1
unnamed: IC3.9 (TS), R29.2
unnamed: C26.2, IC4.2 (DVDT)
unnamed: IC4.3 (EN/UVLO), R33.2, R34.1
unnamed: IC4.7 (ILM), R36.2
unnamed: IC4.8 (OVLO/OVCSEL), R34.2, R35.1
unnamed: C24.1, IC5.6 (VDD), R32.2
unnamed: J1.A5 (CC1), R8.1
unnamed: J1.B5 (CC2), R7.1
unnamed: J2.A5 (CC1), R13.1
unnamed: J2.B5 (CC2), R14.1
unnamed: R1.1, SW1.2 (B)
unnamed: R1.2, R2.1, SW2.2 (B)
unnamed: R2.2, R3.1, SW3.2 (B)
unnamed: R3.2, R4.1, SW4.2 (B)
unnamed: R4.2, R5.1, SW5.2 (B)
unnamed: TP1.1 (1_1), U1.22 (GPIO.10/~RESETOUT)
unnamed: TP2.1 (1_1), U1.29 (I2C_SCL)
unnamed: TP3.1 (1_1), U1.30 (I2C_SDA)
unnamed: R9.2, R10.1, U1.8 (VBUS)
unnamed: R12.2, U1.21 (~CFGMODE)
unnamed: R11.2, U1.9 (~RST)
unnamed: C20.1, U2.6 (BST)
unnamed: C20.2, L1.1, U2.5 (SW)
VBUS: C19.1, IC3.1 (IN), J2.A4 (VBUS), J2.B4 (VBUS)
VDD: C3.1, C4.1, C8.1, IC1.6 (LINEVDD), R6.1, R11.1, R12.1, R15.1, R16.1, U1.6 (VDD)

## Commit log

2026-06-16 File Change/Setup
    [Case_PS - Case_Bottom.step, Case_PS - Case_Top.step, Case_PS - TPU_Band.step]
2026-06-17 Updated BOM
    [Miniamp_PCBA_bom.xls - bom.csv, bom.csv]
2026-06-17 Updated Readme assembly
2026-06-18 cad refresh/almost done readme/new images and renders
    [Case_PS - Case_Bottom.step, Case_PS - Case_Top.step, Case_PS - TPU_Band.step]
2026-06-19 Fianlized all the stuff
    [Miniamp BOM.csv, Miniamp.kicad_pcb, Miniamp.kicad_sch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]
